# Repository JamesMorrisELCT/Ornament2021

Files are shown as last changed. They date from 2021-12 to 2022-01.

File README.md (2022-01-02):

# Ornament2021
Snowflake Ornament Files
Created December 2021 by James Morris

This project is a work in progress at the moment

In this Github directory, you will find the files used to design the PCB, the circuit diagrams, the Bill of Materials, and the arduino code that was used to design the ornament

In order to view the PCB files or the circuit diagram, you will need to have KiCad v5.0+ installed, and then download the project file found under "KiCad Files"

In order to make changes to the arduino code to customiza the lighting sequence of your ornament, you will need to do the following

1. TODO: add instructions on how to upload to lilypad arduino

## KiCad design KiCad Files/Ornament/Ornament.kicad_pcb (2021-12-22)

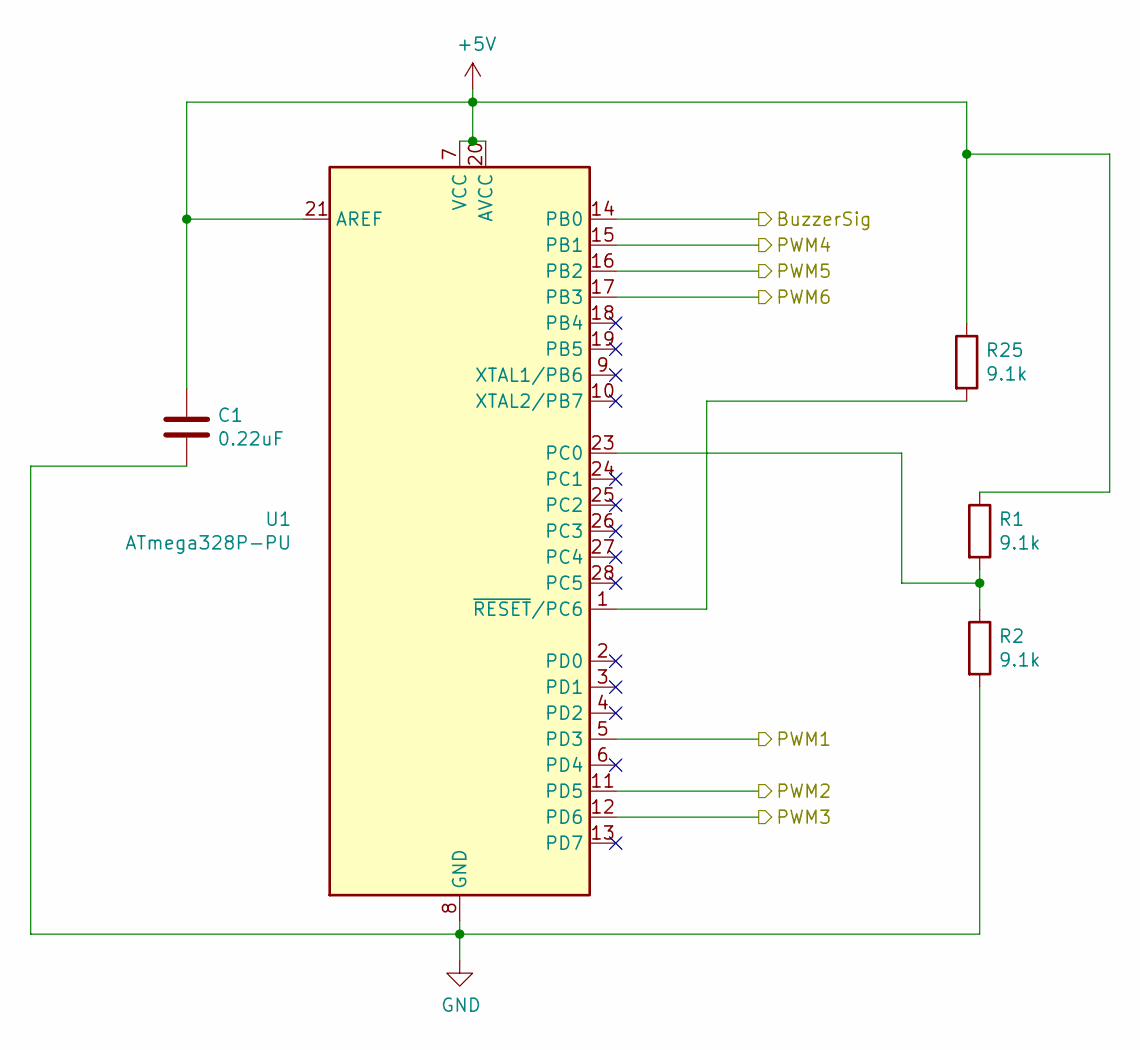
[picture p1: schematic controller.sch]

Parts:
C1: 0.22uF; C_1206_3216Metric_Pad1.33x1.80mm_HandSolder
R1, R2, R25: 9.1k; R_1206_3216Metric_Pad1.30x1.75mm_HandSolder
U1: ATmega328P-PU; DIP-28_W7.62mm_Socket

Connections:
+5V: C1.1, R1.1, R25.1, U1.7 (VCC), U1.20 (AVCC), U1.21 (AREF); also elsewhere on the board
/LED Schematic/Branch1On: U1.5 (PD3); also elsewhere on the board
/LED Schematic/Branch2On: U1.11 (PD5); also elsewhere on the board
/LED Schematic/Branch3On: U1.12 (PD6); also elsewhere on the board
/LED Schematic/Branch4On: U1.15 (PB1); also elsewhere on the board
/LED Schematic/Branch5On: U1.16 (PB2); also elsewhere on the board
/LED Schematic/Branch6On: U1.17 (PB3)
/Power + Other/Buzzer: U1.14 (PB0); also elsewhere on the board
GND: C1.2, R2.2, U1.8 (GND), U1.22 (GND); also elsewhere on the board
unnamed: R1.2, R2.1, U1.23 (PC0)
unnamed: R25.2, U1.1 (~RESET~/PC6)

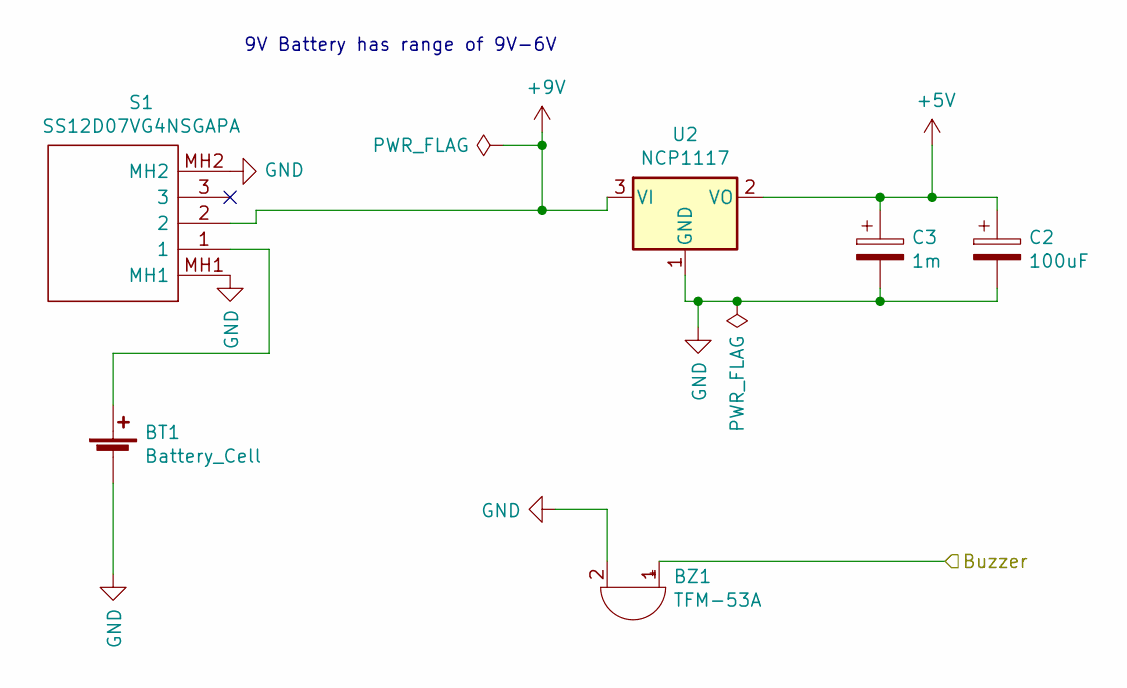
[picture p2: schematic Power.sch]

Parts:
BT1: Battery_Cell; Battery_9V_Connections_Seperate
BZ1: TFM-53A; R_Bare_Metal_Element_L16.3mm_W4.8mm_P15.30mm
C2: 100uF; CP_Radial_D5.0mm_P2.00mm
C3: 1m; C_Radial_D8.0mm_H11.5mm_P3.50mm
S1: SS12D07VG4NSGAPA; Mouser Part Number 611-SS12D07VG4NSGAPA
U2: NCP1117; TO-252-2

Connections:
+5V: C2.1, C3.1, U2.2 (VO); also elsewhere on the board
+9V: S1.2, U2.3 (VI)
/Power + Other/Buzzer: BZ1.1 (-); also elsewhere on the board
GND: BT1.2 (-), BZ1.2 (+), C2.2, C3.2, S1.MH1, S1.MH2, U2.1 (GND); also elsewhere on the board
unnamed: BT1.1 (+), S1.1

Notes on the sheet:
9V Battery has range of 9V-6V

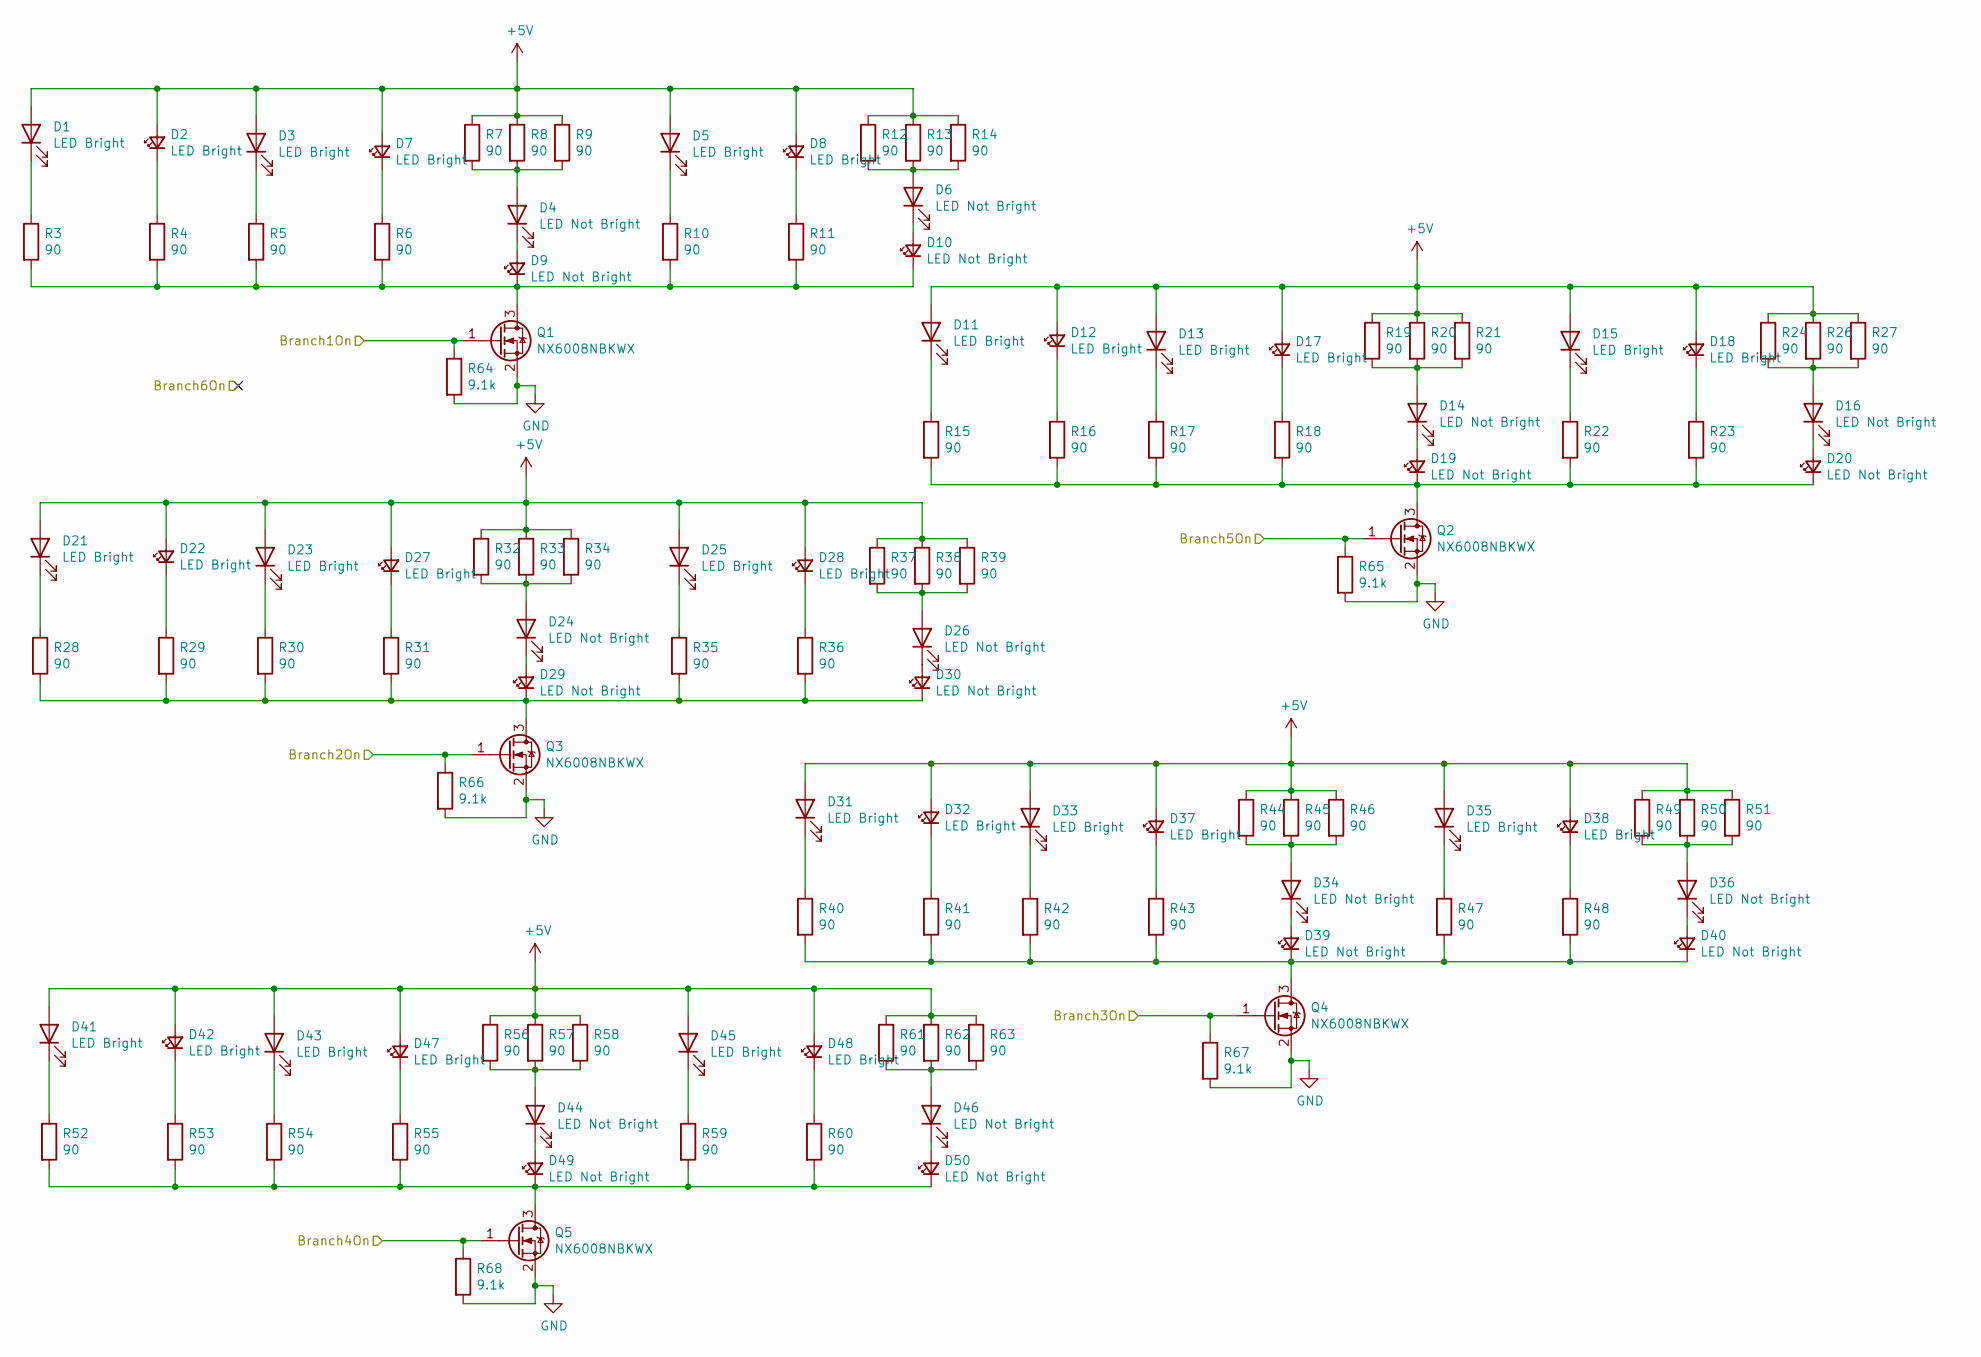
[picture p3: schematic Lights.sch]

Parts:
D1, D3, D5, D11, D13, D15, D21, D23, D25, D31, D33, D35, D41, D43, D45: LED Bright; LED_D5.0mm
D2, D7, D8, D12, D17, D18, D22, D27, D28, D32, D37, D38, D42, D47, D48: LED Bright; LED_1206_3216Metric_Pad1.42x1.75mm_HandSolder
D4, D6, D14, D16, D24, D26, D34, D36, D44, D46: LED Not Bright; LED_D5.0mm
D9, D10, D19, D20, D29, D30, D39, D40, D49, D50: LED Not Bright; LED_1206_3216Metric_Pad1.42x1.75mm_HandSolder
Q1, Q2, Q3, Q4, Q5: NX6008NBKWX; SOT-323_SC-70_Handsoldering
R3, R4, R5, R6, R7, R8, R9, R10, R11, R12, R13, R14, R15, R16, R17, R18, R19, R20, R21, R22, R23, R24, R26, R27, R28, R29, R30, R31, R32, R33, R34, R35, R36, R37, R38, R39, R40, R41, R42, R43, R44, R45, R46, R47, R48, R49, R50, R51, R52, R53, R54, R55, R56, R57, R58, R59, R60, R61, R62, R63: 90; R_1206_3216Metric_Pad1.30x1.75mm_HandSolder
R64, R65, R66, R67, R68: 9.1k; R_1206_3216Metric_Pad1.30x1.75mm_HandSolder

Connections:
+5V: D1.2 (A), D2.2 (A), D3.2 (A), D5.2 (A), D7.2 (A), D8.2 (A), D11.2 (A), D12.2 (A), D13.2 (A), D15.2 (A), D17.2 (A), D18.2 (A), D21.2 (A), D22.2 (A), D23.2 (A), D25.2 (A), D27.2 (A), D28.2 (A), D31.2 (A), D32.2 (A), D33.2 (A), D35.2 (A), D37.2 (A), D38.2 (A), D41.2 (A), D42.2 (A), D43.2 (A), D45.2 (A), D47.2 (A), D48.2 (A), R7.1, R8.1, R9.1, R12.1, R13.1, R14.1, R19.1, R20.1, R21.1, R24.1, R26.1, R27.1, R32.1, R33.1, R34.1, R37.1, R38.1, R39.1, R44.1, R45.1, R46.1, R49.1, R50.1, R51.1, R56.1, R57.1, R58.1, R61.1, R62.1, R63.1; also elsewhere on the board
/LED Schematic/Branch1On: Q1.1 (G), R64.1; also elsewhere on the board
/LED Schematic/Branch2On: Q3.1 (G), R66.1; also elsewhere on the board
/LED Schematic/Branch3On: Q4.1 (G), R67.1; also elsewhere on the board
/LED Schematic/Branch4On: Q5.1 (G), R68.1; also elsewhere on the board
/LED Schematic/Branch5On: Q2.1 (G), R65.1; also elsewhere on the board
GND: Q1.2 (S), Q2.2 (S), Q3.2 (S), Q4.2 (S), Q5.2 (S), R64.2, R65.2, R66.2, R67.2, R68.2; also elsewhere on the board
unnamed: D1.1 (K), R3.1
unnamed: D2.1 (K), R4.1
unnamed: D3.1 (K), R5.1
unnamed: D4.1 (K), D9.2 (A)
unnamed: D4.2 (A), R7.2, R8.2, R9.2
unnamed: D5.1 (K), R10.1
unnamed: D6.2 (A), R12.2, R13.2, R14.2
unnamed: D7.1 (K), R6.1
unnamed: D8.1 (K), R11.1
unnamed: D9.1 (K), D10.1 (K), Q1.3 (D), R3.2, R4.2, R5.2, R6.2, R10.2, R11.2
unnamed: D6.1 (K), D10.2 (A)
unnamed: D11.1 (K), R15.1
unnamed: D12.1 (K), R16.1
unnamed: D13.1 (K), R17.1
unnamed: D14.1 (K), D19.2 (A)
unnamed: D14.2 (A), R19.2, R20.2, R21.2
unnamed: D15.1 (K), R22.1
unnamed: D16.1 (K), D20.2 (A)
unnamed: D16.2 (A), R24.2, R26.2, R27.2
unnamed: D17.1 (K), R18.1
unnamed: D18.1 (K), R23.1
unnamed: D19.1 (K), D20.1 (K), Q2.3 (D), R15.2, R16.2, R17.2, R18.2, R22.2, R23.2
unnamed: D21.1 (K), R28.1
unnamed: D22.1 (K), R29.1
unnamed: D23.1 (K), R30.1
unnamed: D24.1 (K), D29.2 (A)
unnamed: D24.2 (A), R32.2, R33.2, R34.2
unnamed: D25.1 (K), R35.1
unnamed: D26.1 (K), D30.2 (A)
unnamed: D26.2 (A), R37.2, R38.2, R39.2
unnamed: D27.1 (K), R31.1
unnamed: D28.1 (K), R36.1
unnamed: D29.1 (K), D30.1 (K), Q3.3 (D), R28.2, R29.2, R30.2, R31.2, R35.2, R36.2
unnamed: D31.1 (K), R40.1
unnamed: D32.1 (K), R41.1
unnamed: D33.1 (K), R42.1
unnamed: D34.1 (K), D39.2 (A)
unnamed: D34.2 (A), R44.2, R45.2, R46.2
unnamed: D35.1 (K), R47.1
unnamed: D36.1 (K), D40.2 (A)
unnamed: D36.2 (A), R49.2, R50.2, R51.2
unnamed: D37.1 (K), R43.1
unnamed: D38.1 (K), R48.1
unnamed: D39.1 (K), D40.1 (K), Q4.3 (D), R40.2, R41.2, R42.2, R43.2, R47.2, R48.2
unnamed: D41.1 (K), R52.1
unnamed: D42.1 (K), R53.1
unnamed: D43.1 (K), R54.1
unnamed: D44.1 (K), D49.2 (A)
unnamed: D44.2 (A), R56.2, R57.2, R58.2
unnamed: D45.1 (K), R59.1
unnamed: D46.1 (K), D50.2 (A)
unnamed: D46.2 (A), R61.2, R62.2, R63.2
unnamed: D47.1 (K), R55.1
unnamed: D48.1 (K), R60.1
unnamed: D49.1 (K), D50.1 (K), Q5.3 (D), R52.2, R53.2, R54.2, R55.2, R59.2, R60.2

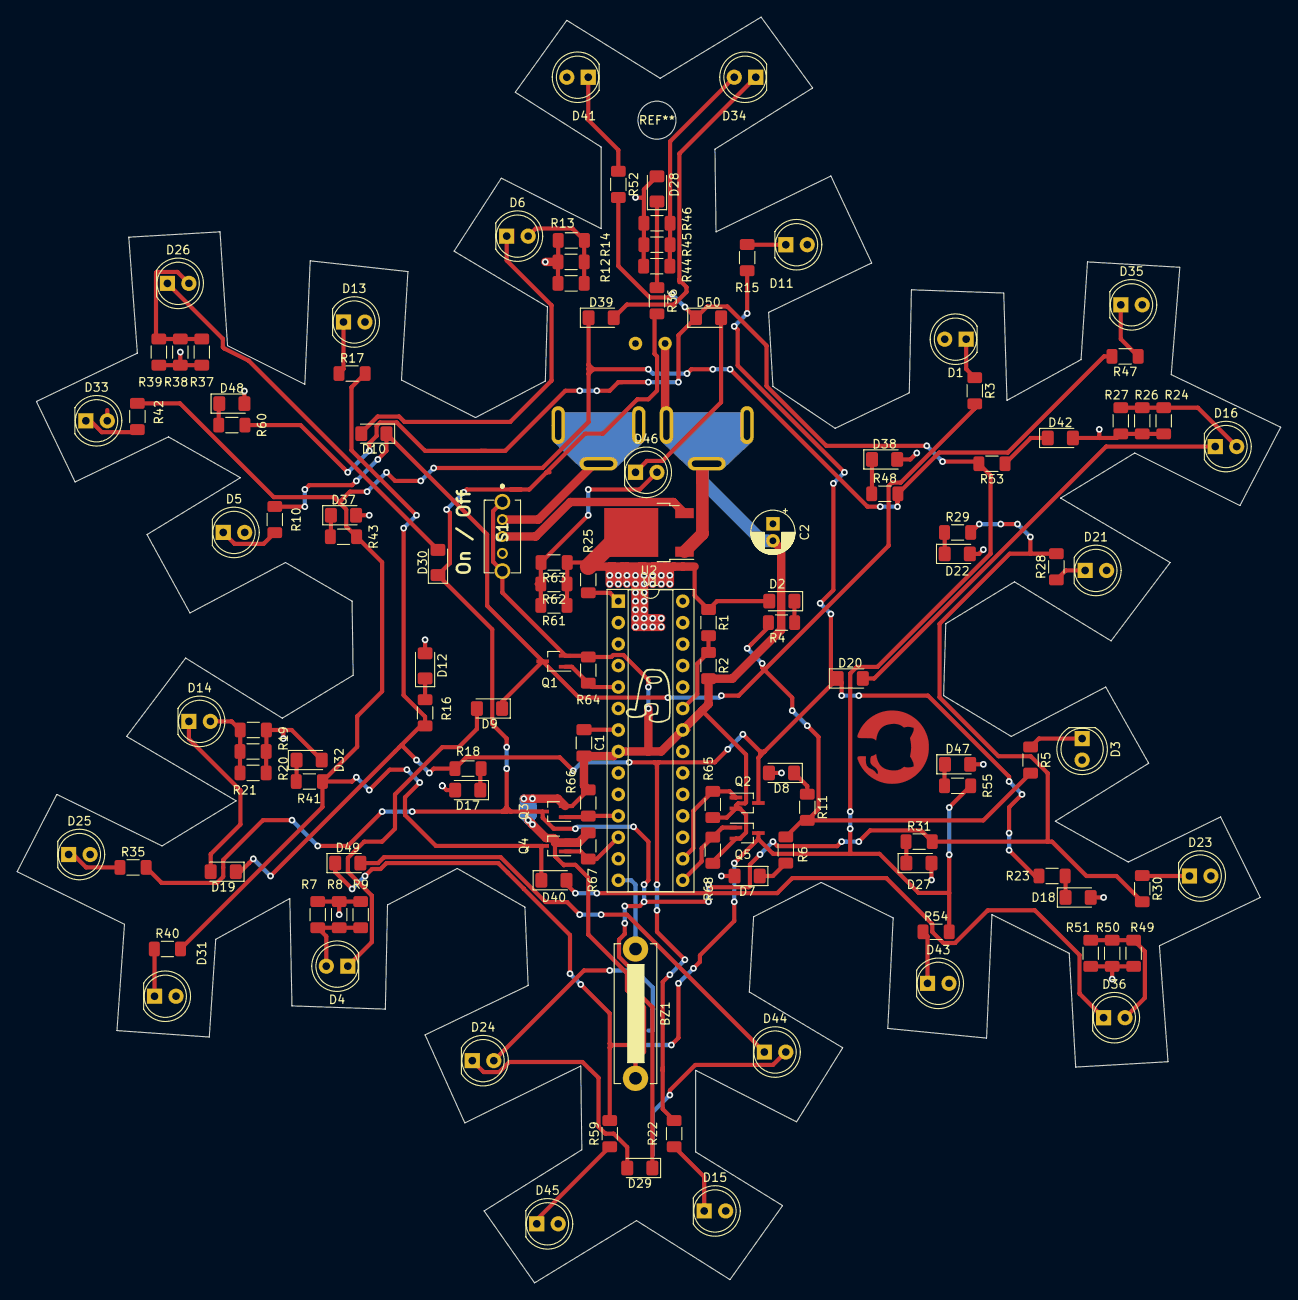
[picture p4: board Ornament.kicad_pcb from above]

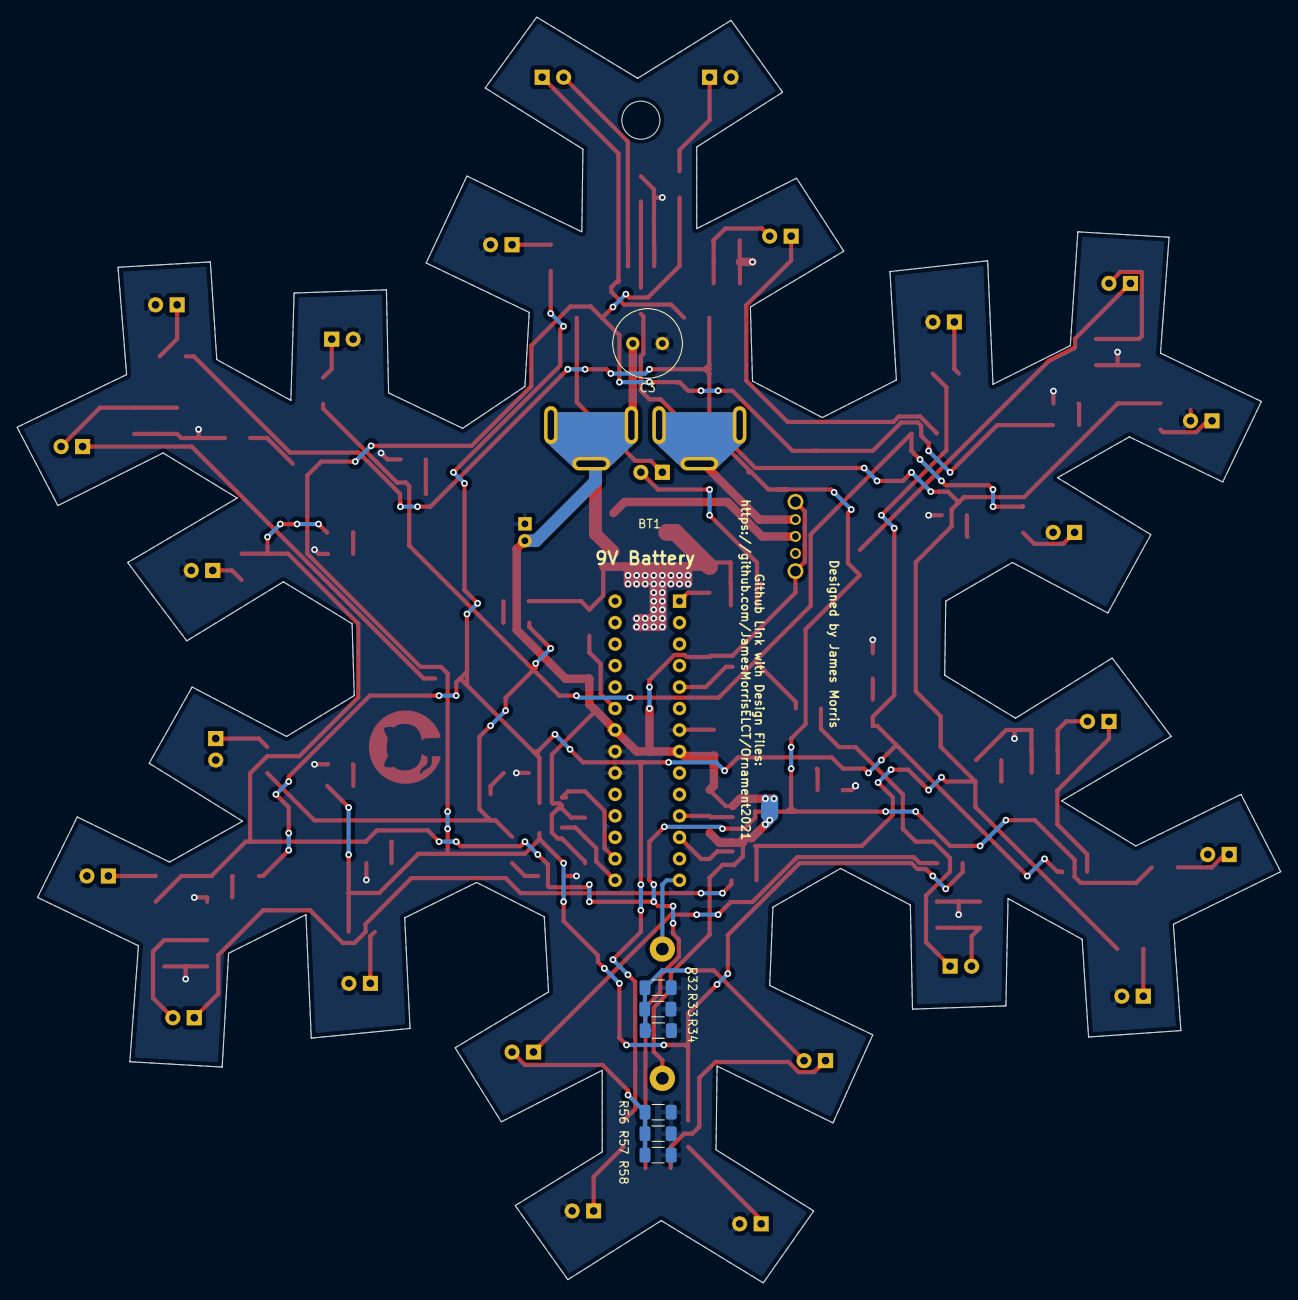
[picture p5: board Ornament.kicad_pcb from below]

Board: 2 copper layers, 149.5 x 149.7 mm, 131 parts (8 on the bottom side), 67 nets.

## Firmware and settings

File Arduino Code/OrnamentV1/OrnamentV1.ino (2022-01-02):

/*      Christmas Ornament v1
 *      Code constructed by James Morris - December 2021
 *      All design files including PCB design and arduino code can be found at https://github.com/JamesMorrisELCT/Ornament2021
 *      This code is as it was distrubuted on the ornaments
 */


//Creating references for the output control registers so that the code is easier to understand, each one controls the PWM of a single channel
volatile uint8_t& section1 = OCR0A;
volatile uint8_t& section2 = OCR0B;
volatile uint16_t& section3 = OCR1A;
volatile uint16_t& section4 = OCR1B;
volatile uint8_t& section5 = OCR2B;
//volatile uint8_t& section6 = OCR2A;

//OnValue changes the maximum brightness of the LEDs
int onValue = 10; // Maximum value of PWM  maximum possible is 255, minimum is 1

uint8_t mode;  //Mode of lighting
               // Only a single mode has been included with v1

int delayTime=100;  //Time in arbitrary unit (dependent on Clock speed) that is referenced for the blinking timing (make lower for faster, larger for slower)

void setup() {

  //TODO: Add support for a pushbutton that switched modes

  //Setting the pins as outputs
  pinMode(PD6, OUTPUT);   //OC0A
  pinMode(PD5, OUTPUT);   //OC0B
  pinMode(PB1, OUTPUT);   //OC1A
  pinMode(PB2, OUTPUT);   //OC1B
  pinMode(PD3, OUTPUT);   //OC2B
  //pinMode(PB3, OUTPUT); //OC2A UNUSED ATM

  setupPWM();
  findTurnOnValue();

  mode=0;

}

void loop() {
  if(mode==0){
    //Simple routine that just turns on each channel for a set time one at a time
    turnOn(section1);
    delay(delayTime);
    allOff();
    turnOn(section2);
    delay(delayTime);
    allOff();
    turnOn(section3);
    //section3=onValue;
    delay(delayTime);
    allOff();
    turnOn(section4);
    //section4=onValue;
    delay(delayTime);
    allOff();
    turnOn(section5);
    delay(delayTime);
    allOff();
  } else {
    allOff();
  }
}


void turnOn(volatile uint8_t& reg){ //Turns on a specific channel
  reg=onValue;
}

void turnOn(volatile uint16_t& reg){ //Turns on a specific channel
  reg=onValue;
}

void turnOff(volatile uint8_t& reg){  //Turns off a specific channel
  reg=0;
}

void turnOff(volatile uint16_t& reg){  //Turns off a specific channel
  reg=0;
}

void allOff() { //Turns all the channels off
  section1=0;
  section2=0;
  section3=0;
  section4=0;
  section5=0;
}

void setupPWM(){ //Sets up the Timer0 Timer1 and Timer2 registers to support the 8 bit fast PWM mode on each
  TCCR0A = _BV(COM0A1) | _BV(COM0B1) | _BV(WGM21) | _BV(WGM20);
  TCCR0B = _BV(CS22);
  TCCR2A = _BV(COM2A1) | _BV(COM2B1) | _BV(WGM21) | _BV(WGM20);
  TCCR2B = _BV(CS22);

  TCCR1A = (1<<COM1A1) + (1<<COM1B1) + (1<<WGM10); //non inverting A and B outputs, mode 5 (fast pwm 8 bit)
  TCCR1B = (1<<WGM12) + (1<<CS12); // prescaler = 256
  DDRB |= (1<<PB1)|(1<<PB2);

  allOff();
}

void testFCLK(volatile uint8_t& reg){ //OBSOLETE
  noInterrupts();
  reg = _BV(CLKPCE); // 0x80
  reg = _BV(CLKPS3); // 0x03
  interrupts();
}

void findTurnOnValue(){
  //TODO change on value depending on number of times power has been cycled using EEPROM
  onValue=10;
}
